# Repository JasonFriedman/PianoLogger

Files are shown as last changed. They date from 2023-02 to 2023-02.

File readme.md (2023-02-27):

This project provides details for how to build an Arduino-based piano logger - it logs every key press on a MIDI keyboard. The device does not measure any other input (i.e., no microphone or other sensors). The files are saved to a CSV file

The project consists of:
1. [Parts list](PartsList.md) - a list of parts needed for the project
2. STL and openSCAD files for the 3D needed for the box
3. Arduino code
4. [Construction instructions](constructionInstructions.md)

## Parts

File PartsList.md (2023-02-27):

**Parts list**

Note that all of the parts can be purchased from other retailers, the cost / URL is provided as an example of where the part can be purchased from. Prices are from February 2023 and may change.

| Part name | Description | Cost | URL |
| --- | --- | --- | --- |
| Arduino Uno or compatible | Microcontroller | $10 | https://www.banggood.com/UNO-R3-ATmega328P-Development-Board-Geekcreit-for-Arduino-products-that-work-with-official-Arduino-boards-p-963697.html |
| Data logger shield | Arduino shield with an SD card slot and a battery (to keep the date / time accurate) | $4 | https://www.banggood.com/UNO-R3-ATmega328P-Development-Board-Geekcreit-for-Arduino-products-that-work-with-official-Arduino-boards-p-963697.html |
| USB host shield | Arduino shield with USB host to connect to keyboard | $15 | https://www.banggood.com/USB-Host-Shield-Compatible-For-Google-Android-ADK-Support-U-NO-MEGA-Module-p-1384907.html |
| USB A to USB B cable | provide power to the Arduino (connectors may vary on other models) | $4 | https://www.banggood.com/Veggieg-USB2_0-Printer-Data-Cable-High-Speed-Type-A-to-B-Male-to-Male-Cable-for-Printers-Scanners-Computers-TV-Fax-Machine-All-in-one-Machin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 |
| USB A to Micro USB cable | Connect from the host shield to the keyboard. This connect may vary on different keyboards | $8 | https://www.banggood.com/BlitzWolf-BW-MC14-Micro-USB-Charging-Data-Cable-6ft-or-1_8m-For-Samsung-S7-S6-Note-5-p-1339803.html |
| 5mm 3-pin Red-green LED | To provide status information (note this a pack of 100, 1 will do!) | $7 | https://www.ebay.com/itm/221404513700 |
| 5mm LED plastic mounting clip | To mount the LED (also a pack of 100, 1 will do) | $3.50 | https://www.ebay.com/itm/261841171472 |
| 100 ohm resistor | To use the with green LED (to reduce the voltage to the appropriate level). (Note the link is to an assorted pack of 600, 1 will do!)  | $5 | https://www.banggood.com/Wholesale-Geekcreit-600pcs-30-Kinds-Value-1-pencent-1-or-4W-Metal-Film-Resistor-Assorted-Kit-20pcs-Each-Value-p-53320.html |
| 150 ohm resistor | To use the with red LED (to reduce the voltage to the appropriate level) | | see above|
| Heat shrink | To isolate the resistors to prevent short circuit (note this a large assorted pack, 2 pieces will do) | $9 | https://www.banggood.com/530Pcs-Heat-Shrink-Tubing-Insulation-Shrinkable-Tubes-Assortment-Electronic-Polyolefin-Wire-Cable-Sleeve-Kit-Heat-Shrink-p-1748260.html |
| SD card | Store the key presses for later analysis | $10 | https://www.banggood.com/BlitzWolf-BW-MC14-Micro-USB-Charging-Data-Cable-6ft-or-1_8m-For-Samsung-S7-S6-Note-5-p-1339803.html |
| Power supply for arduino | Provide 5V to run the arduino | $11 | https://www.banggood.com/Universal-5V-2A-USB-EU-Wall-Charger-Adapter-For-Mobile-Phone-p-1979567.html |
| CR1220 battery | for the data loggers, so that it can mantain the date / time | $2 | available at many locations |
| M2 screws and nuts| To attach the arduino to the case to prevent it moving around |

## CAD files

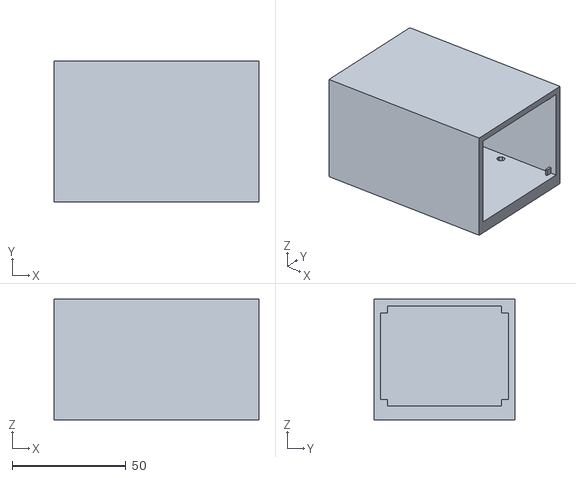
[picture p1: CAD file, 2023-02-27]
3Dparts/uno_box.stl
90.0 x 62.0 x 53.0

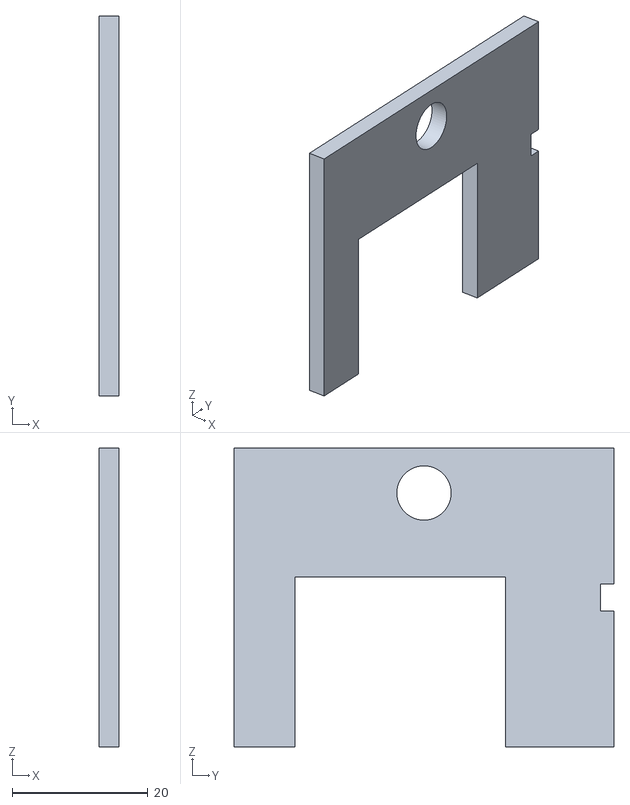
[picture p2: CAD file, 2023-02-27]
3Dparts/uno_box_lid.stl
3.00 x 56.0 x 44.0

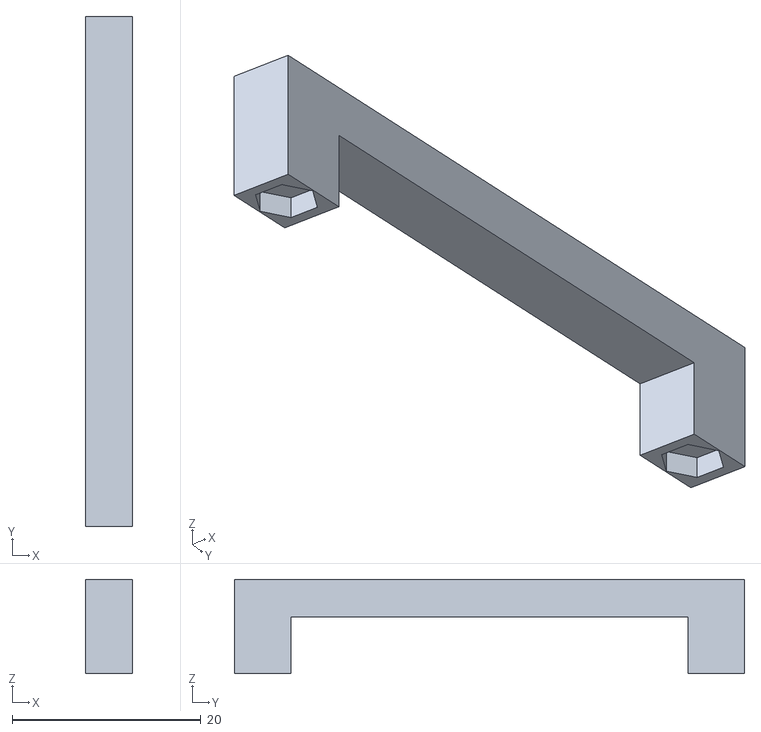
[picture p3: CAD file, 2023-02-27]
3Dparts/uno_screw_holder.stl
5.00 x 54.0 x 10.0

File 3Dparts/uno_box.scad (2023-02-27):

wallthickness = 3;
bottomthickness = 6;

length = 90;
width = 62;
height = 53;

holewidth = 48;
hole1radius = 2;
holesidedistance = (width - holewidth)/2;
hole2radius = 3;

difference(){ 
    cube([length,width,height]);
    union() {
    translate([3+wallthickness,wallthickness,bottomthickness])
    cube([length-(wallthickness*2)+1,width-(wallthickness*2),height-(wallthickness+bottomthickness)]);
    
    translate([60,holesidedistance,3]) cylinder(h=10,r=hole1radius);
    translate([60,holesidedistance,-1]) cylinder(h=4,r=hole2radius);
        
    translate([60,width-holesidedistance,3]) cylinder(h=10,r=hole1radius);
    translate([60,width-holesidedistance,-1]) cylinder(h=4,r=hole2radius);
    }
}

// Add 4 small pieces to stop the lid from falling in
translate([length-3-1,wallthickness,bottomthickness])
cube([1,3,3]);

translate([length-3-1,width-wallthickness-3,bottomthickness])
cube([1,3,3]);

translate([length-3-1,wallthickness,height-3-wallthickness])
cube([1,3,3]);

translate([length-3-1,width-wallthickness-3,height-3-wallthickness])
cube([1,3,3]);

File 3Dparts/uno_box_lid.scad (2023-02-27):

wallthickness = 3;
bottomthickness = 6;

length = 90;
width = 62;
height = 53;

squeezeFactor = 0;
LEDholeradius = 4;

depth =3;

inner_width  = width-(wallthickness*2)-squeezeFactor;
inner_height = height-(wallthickness+bottomthickness) - squeezeFactor;

difference(){
cube([depth,inner_width,inner_height]);
    union() {
         translate([-1,inner_width/2,inner_height*0.85]) 
         rotate([0,90,0])
         cylinder(h=10,r=LEDholeradius,$fn = 60);
         
         // For the cables: From y = 9 to 40 mm, from z = 0 to 25 mm
         translate([-1,9,-1])
         cube([10,31,25+1]);
        
        // Hole to put a (small) screwdriver in to pull it out
        // 4 mm by 2 mm
        translate([-1,inner_width-2,inner_height/2-2])
        cube([10,2+1,4]);
    }
}

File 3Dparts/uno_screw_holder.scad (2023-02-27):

// Note: this requires the library from here: https://github.com/b33j0r/Metric
use <Metric/M2.scad>;

uno_width = 53;
width = uno_width + 1;

depth = 5;
height = 10;

holedepth = depth;
holewidth = 42;
holeheight = 6;

holedistance = 48;

difference() {
    cube([depth,width,height]);
    union() {
        translate([-1,(width-holewidth)/2,-1])
        cube([depth+2,holewidth,holeheight+1]);
        
        translate([depth/2,(width-holedistance)/2,1.55])
        NutM2();
        
        translate([depth/2,width-(width-holedistance)/2,1.55])
        NutM2();


    }
}

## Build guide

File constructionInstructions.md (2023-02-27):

# Construction instructions

- 3D print the three pieces
- Purchase / obtain the rest of the parts from the [Parts list](PartsList.md)

You will need a soldering iron, some wire, and a little experience for this part

## Bottom layer:
- The bottom layer is the UNO board (this does not require any modifications)

## Middle layer:
- The middle layer is the USB host shield.
-  Cut the solder jumper connector of SS, and solder a wire from SS to pin 2 (4th from the end, NOT on the side with the reset button)
- Solder the 3.3V and 5V jumpers (next to the reset button), and the 5V jumper next to where it is written VBUS PWR
(this is due to manufacturing issues with these boards, see an [explanation](https://esp8266-notes.blogspot.com/2017/08/defective-arduino-usb-host-shield-boards.html) )

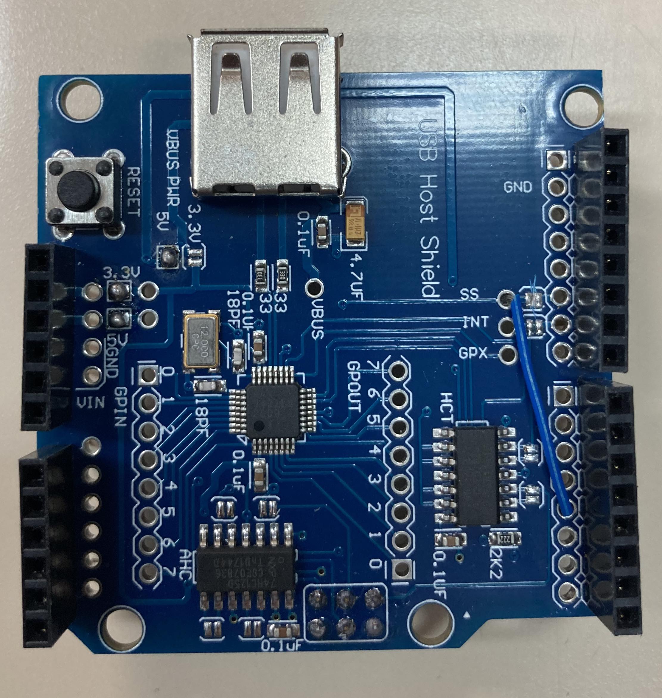
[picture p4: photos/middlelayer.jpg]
photo of the middle layer Middle layer


## Front piece:
- The front piece holds the LED. Place the red-green LED in the mounting clip, and mount it in the front piece. Solder the three legs as follows:
  * shortest leg (green) to the 100 ohm resistor then to a piece of wire
  * middle length (red) to the 150 ohm resistor then to a piece of wire
  * longest leg to a piece of wire
- Place shrink wrap around the resistors and the connections

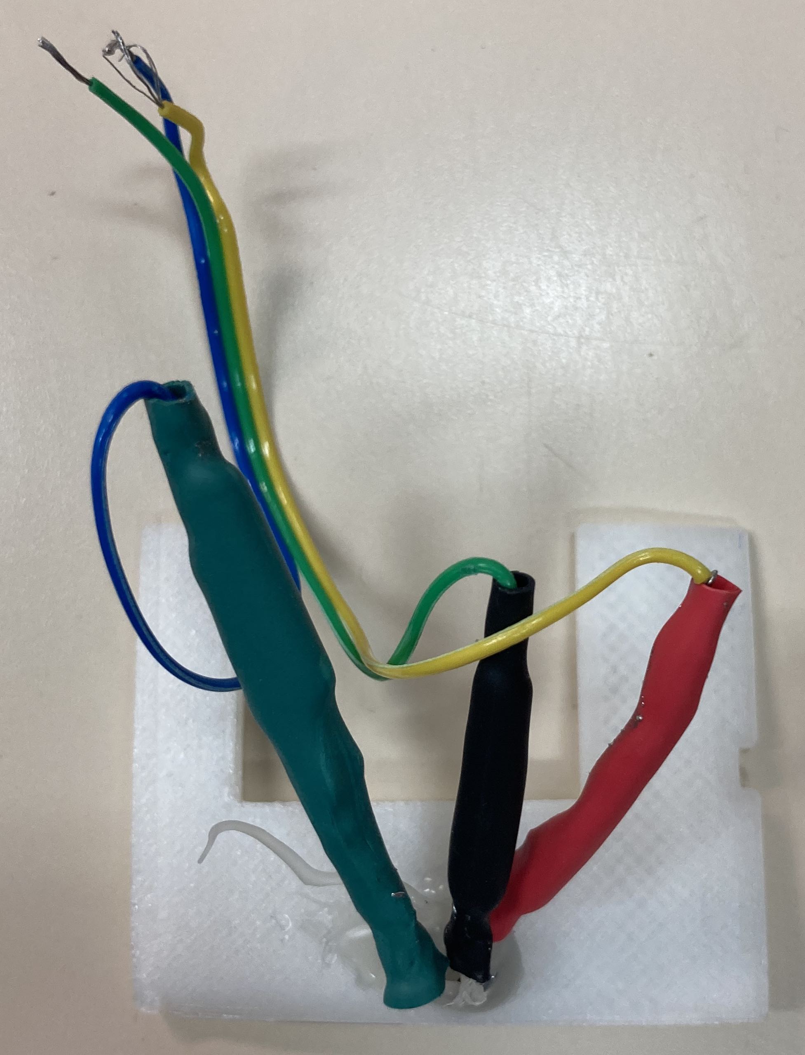
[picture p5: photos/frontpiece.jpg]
photo of the front piece Front piece


## Top layer:
- The top layer is the data logging shield
- Make sure there is a battery in the holder (will need to then set the time)
- Solder CD to pin 4 (on the side of the board with the reset button)
- Solder the connection from the green LED (shortest leg), i.e. after the resistor, to pin 7 
- Solder the connection from the red LED (middle length), i.e. after the resistor, to pin 8 
- Solder the connection from the ground (longest leg) to a GND pin 
- Bend the IOREF and RST pins (next to the battery), and the SCL and SDA pins so it fits on the USB host shield

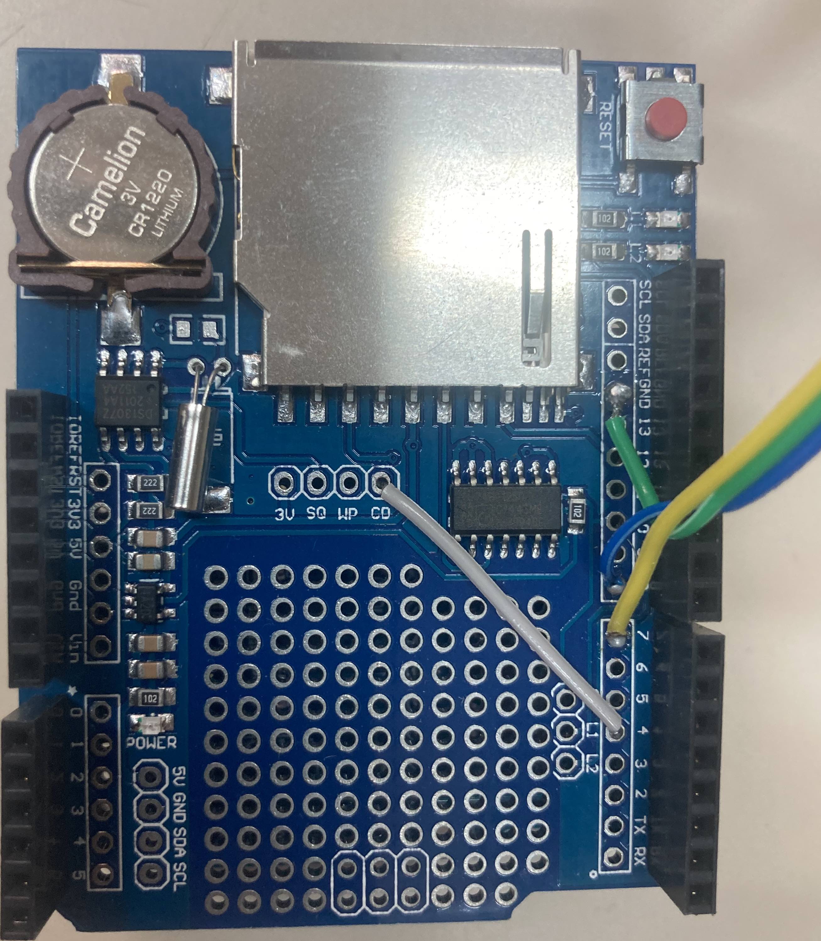
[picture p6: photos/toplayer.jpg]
photo of the top layer Top layer


## Combining the pieces
- Once the three pieces are joined they should be placed inside the box. Place the M2 nuts in the holes in the screw holder. Slide the board inside the box. Hold the screw holder with one hand (to keep the nuts in place), and insert the screws from underneath (and tighten them)

- The front piece is held on by friction, there is a small hole to pry it off using a small screwdriver or similar

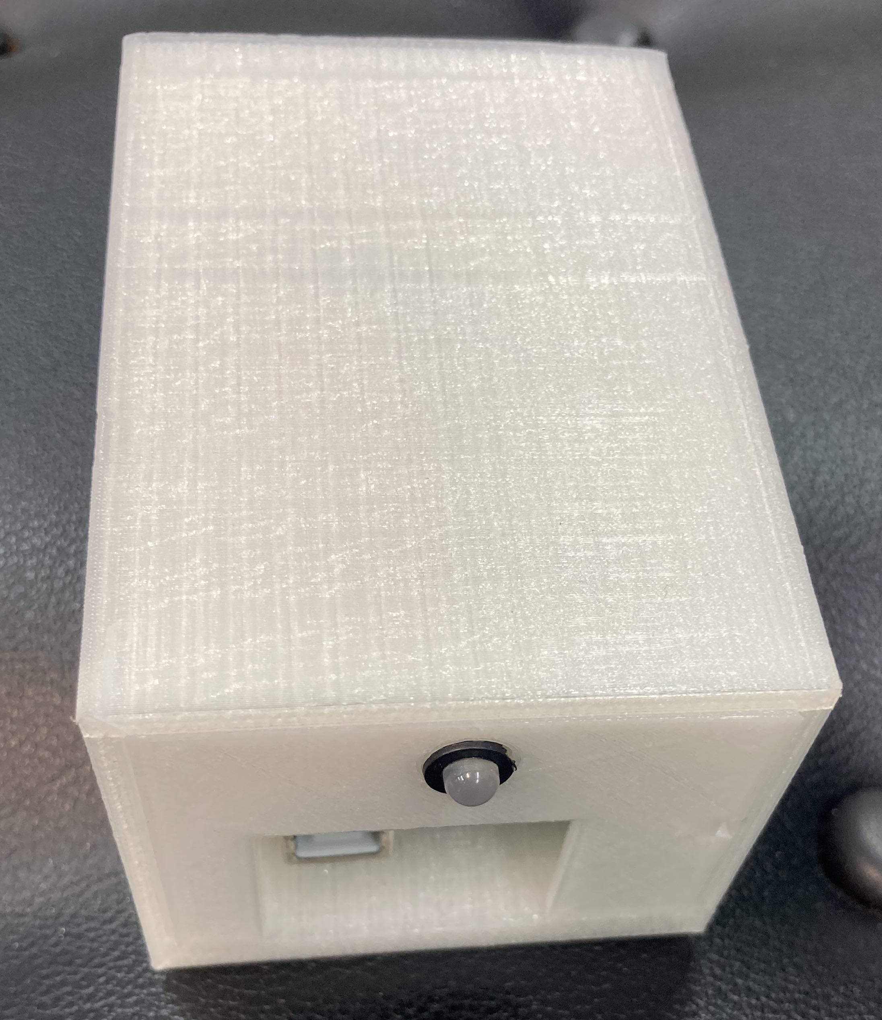
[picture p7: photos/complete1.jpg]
photo of the built device The built device

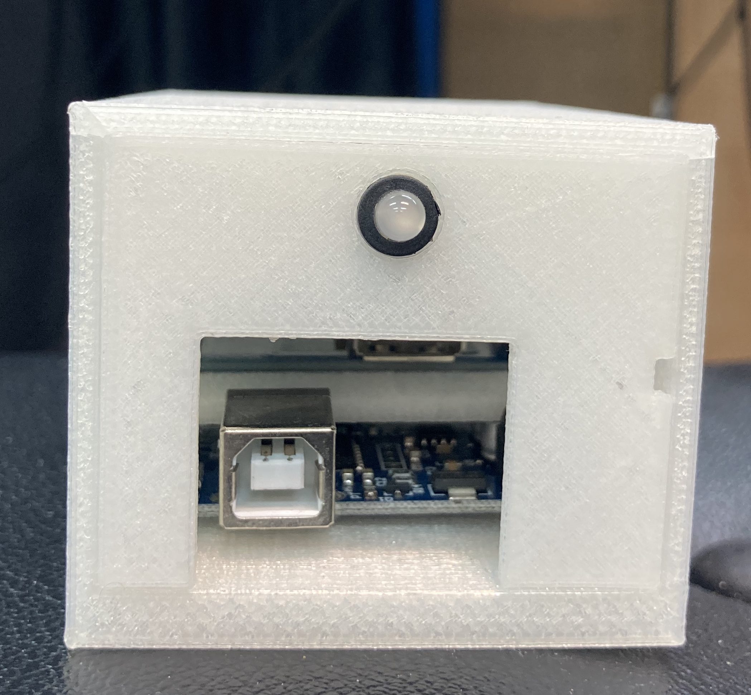
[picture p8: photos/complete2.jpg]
photo of the built device The built device


## Arduino

- Connect the board to a computer. In the arduino IDE, you will need to install the following libraries:
  * Time
  * DS1307RTC
  * SdFat
  * USB Host Shield Library v2.0
- Note that you need to change one line in one of the libraries:
  * In the file UsbCore.h (in Documents/Arduino/libraries/USB_Host_Shield_Library_2.0) this line to:

// typedef MAX3421e<P3, P9> MAX3421E; // Official Arduinos (UNO, Duemilanove, Mega, 2560, Leonardo, Due etc.), Intel Edison, Intel Galileo 2 or Teensy 2.0 and 3.x

- Before first use or if the battery is replaced, the date and time needs to be set. This can be performed using the example program "TimeRTCSet" from the [time library](https://github.com/PaulStoffregen/Time), note that you will also need to run the Processing script

# Usage
- Now the keyboard can be connected. It can be powered from the computer, or using a USB wall adapter. For testing, it is recommended first to use it with a computer so you can see that the notes are being recorded (using the serial monitor in the Arudino IDE)

- The device will create a new comma separated file (.csv) file for every day that it is used. The files will contain a time stamp, the event (key press or key release), and the volume (if this is not supported, the same number will appear on every line) 

- The format of the file is as follows:
  * Date DD/MM/YYYY format
  * time HH:MM:SS.SSS format
  * event: 1 = press, 2 = release
  * channel
  * note (according to standard MIDI notes, e.g. 60 is middle C)
  * volume (if supported, otherwise will always be the same value)

For example:

13/09/2022,09:52:58.648,1,000,060,100

13/09/2022,09:52:58.650,2,000,060,064

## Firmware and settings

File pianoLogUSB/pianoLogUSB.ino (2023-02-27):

// NOTE: NEED TO CHANGE UsbCore.h (in Documents/Arduino/libraries/USB_Host_Shield_Library_2.0) this line to:
// typedef MAX3421e<P3, P9> MAX3421E; // Official Arduinos (UNO, Duemilanove, Mega, 2560, Leonardo, Due etc.), Intel Edison, Intel Galileo 2 or Teensy 2.0 and 3.x

// Bottom layer is the UNO board

// Middle layer is the USB host shield
// Need to cut the solder jumper connector of SS, and solder a wire from SS to pin 2 (4th from the end, NOT on the side with the reset button)
// Need to solder the 3.3V and 5V jumpers (next to the reset button), and the 5V jumper next to where is it written VBUS PWR

// Top layer is the data logging shield
// Make sure there is a battery in the holder (will need to then set the time)
// Solder CD to pin 4 (on the side of the board with the reset button)
// Bend the IOREF and RST pins (next to the battery), and the SCL and SDA pins so it fits on the USB host shield

#include <SPI.h>
#include <TimeLib.h>
#include <DS1307RTC.h> 
#include <SdFat.h>
// The next two are to check for memory issues
//#include <MemoryFree.h>
//#include <pgmStrToRAM.h>

#include <usbh_midi.h>
#include <usbhub.h>

// red/green LED, from ebay page:
// Red forward voltage: 1.8 ~ 2.2
// Green forward voltage: 3.0 ~ 3.4
// Maximum continuous forward current: 20 mA
// For 2.0 V, need 150 ohm
// for 3.2 V, need 91 ohm (use 100 ohm)
#define RED_LED 8   // middle length - 150 ohm
#define GREEN_LED 7 // the shortest lead - 100 ohm
// longest lead is the ground

USB Usb;
//USBHub Hub(&Usb);
USBH_MIDI  Midi(&Usb);

const uint8_t SDchipSelect = 10;
const uint8_t cardDetect = 4;
SdFat sd;


time_t starttime;
long startMillis;

File fd;
char fileName[13]; // SD library only supports up to 8.3 names
bool alreadyBegan = false;  // SD.begin() misbehaves if not first call

bool writeError = true;

long lastswitch = -1;

void setup() {
  pinMode(3,OUTPUT);
  pinMode(4,INPUT);
  pinMode(10,OUTPUT);
  pinMode(cardDetect, INPUT_PULLUP);

  pinMode(RED_LED,OUTPUT);
  pinMode(GREEN_LED,OUTPUT);

  // Start with it red
  digitalWrite(RED_LED,1);
  digitalWrite(GREEN_LED,0);

  if (Usb.Init() == -1)
    Serial.println(F("OSC did not start."));

  setSyncProvider(RTC.get);

  Serial.begin(115200);
  Serial.println(F("Piano logger"));

  // Get the time from the RTC and the current millis
  starttime = now();
  long startMillis = millis();

  // Connect to the SD card
  initializeCard();
}

void loop() {
  Usb.Task();
  if ( Usb.getUsbTaskState() == USB_STATE_RUNNING )
  {
    MIDI_poll();
    digitalWrite(RED_LED,0);
    digitalWrite(GREEN_LED,1);
  }
  else {
    // MIDI is disconnected - set the red light
    digitalWrite(RED_LED,1);
    digitalWrite(GREEN_LED,0);
    return;
  }
    
  time_t timeNow = now();
  // only need to check if the 2nd character (of the day) is different
  int thisday = day(timeNow);
  if (thisday % 10 +48 != (int) fileName[1])
    setFileName();

  if (writeError) {
     long timepassed = millis() - lastswitch;
      if (timepassed<500) {
        digitalWrite(RED_LED,1);
        digitalWrite(GREEN_LED,0);
      }
      else if (timepassed<1000) {
        digitalWrite(RED_LED,0);
        digitalWrite(GREEN_LED,0);
      }
      else {
        // reset the counter
        lastswitch = millis();
        digitalWrite(RED_LED,1);
        digitalWrite(GREEN_LED,0);
      }
  } else {
    lastswitch = -1;
    digitalWrite(RED_LED,0);
    digitalWrite(GREEN_LED,1);
  }
}

void MIDI_poll()
{
  uint16_t  rcvd;
  uint8_t bufMidi[65];
  delay(10);
  
  if (Midi.RecvData( &rcvd,  bufMidi) == 0 ) {
    uint8_t command = ((uint8_t)bufMidi[1])/16;
    uint8_t channel = ((uint8_t)bufMidi[1])%16;
    uint8_t note = (uint8_t)bufMidi[2];
    uint8_t velocity = (uint8_t)bufMidi[3];
    if (command==9)
      handleNoteOn(channel,note,velocity);
    
    else if (command==8)
       handleNoteOff(channel,note,velocity);
    else
       Serial.println(F("Ignoring other MIDI command"));  
      // Ignore other commands for now 
  }
}

void handleNoteOn(uint8_t inChannel, uint8_t inNote, uint8_t inVelocity)
{ 
  char s[38];
  printTime(s);
  snprintf_P(s+23,
             15,
             PSTR(",1,%03d,%03d,%03d"),
             inChannel, inNote, inVelocity); // 1 = on
  Serial.println(s);
  digitalWrite(RED_LED,1);
  digitalWrite(GREEN_LED,0);
  writeToSDCard(s);
  digitalWrite(RED_LED,0);
  //Serial.print(F("Free RAM = "));
  //Serial.println(freeMemory(), DEC);
}

void handleNoteOff(uint8_t inChannel, uint8_t inNote, uint8_t inVelocity)
{
  char s[38];
  printTime(s);
  snprintf_P(s+23,
             15,
             PSTR(",2,%03d,%03d,%03d"),
             inChannel, inNote, inVelocity); // 2 = off
  Serial.println(s);
  digitalWrite(RED_LED,1);
  digitalWrite(GREEN_LED,0);
  writeToSDCard(s);
  digitalWrite(RED_LED,0);
  //Serial.print(F("Free RAM = "));
  //Serial.println(freeMemory(), DEC);
}

int getTime(time_t* newtime) {
  // Get the time
  long timediff = millis() - startMillis;
  uint32_t newtimeSeconds = starttime + timediff / 1000;
  int ms = timediff % 1000;
  return ms;
}

// datestring should be a char array with size at least 24 (23 characater + null terminator)
void printTime(char* datestring) {
  time_t newtime = now();
  int ms = getTime(&newtime);

  snprintf_P(datestring,
             24,
             PSTR("%02u/%02u/%04u,%02u:%02u:%02u.%03u"),
             day(newtime),
             month(newtime),
             year(newtime),
             hour(newtime),
             minute(newtime),
             second(newtime),
             ms);
}

void initializeCard(void)
{
  Serial.print(F("Initializing SD card..."));

  // Is there even a card?
  // On this board - cardDetect is 0 means there is a card
  if (digitalRead(cardDetect))
  {
    Serial.println(F("No card detected. Waiting for card."));
    while (digitalRead(cardDetect)) {
        digitalWrite(RED_LED,1);
        digitalWrite(GREEN_LED,0);
        delay(500);
        digitalWrite(RED_LED,0);
        delay(500);
    }
    delay(250); // 'Debounce insertion'
  }

  // Card seems to exist. 
  while (!sd.begin(SDchipSelect))  // begin uses half-speed...
  {
    Serial.println(F("Initialization failed!"));
    digitalWrite(RED_LED,1);
    digitalWrite(GREEN_LED,0);
    delay(500);
    digitalWrite(RED_LED,0);
    delay(500);
  }
  Serial.println(F("Initialization done."));

  setFileName();

  Serial.print(fileName);
  if (sd.exists(fileName))
  {
    Serial.println(F(" exists."));
  }
  else
  {
    Serial.println(F(" doesn't exist. Creating."));
  }

  Serial.print(F("Opening file: "));
  Serial.println(fileName);

  // Set the LED to green after connection
  writeError = false;
}

void writeToSDCard(char* message) {
  fd = sd.open(fileName, FILE_WRITE);
  if (fd) {
    fd.println(message);
    //fd.flush(); // This is done automatically when the file is closed
    fd.close();
    writeError = false;
  }
  else {
    Serial.println(F("*** Did not succeed to write to SD card ***"));
    writeError = true;
  }
}

void setFileName() {
  // fileName based on the date
  time_t newtime = now();

  snprintf_P(fileName,
             13,
             PSTR("%02u%02u%04u.csv"),
             day(newtime),
             month(newtime),
             year(newtime));
  Serial.print(F("Set filename to "));
  Serial.println(fileName);
}
